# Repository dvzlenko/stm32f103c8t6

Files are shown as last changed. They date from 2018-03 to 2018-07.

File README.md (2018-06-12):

| stm32f103c8t6 | что подключать		|
|---|---|
| A8		| PWM_00			|
| A9		| PWM_01			|
| B12		| SENS_00			|
| B13		| SENS_01			|
| B14		| SENS_02			|
| B15		| SENS_03			|
| B8		| PWM_10			|
| B9		| PWM_11			|
| B6		| SENS_10			|
| B7		| SENS_11			|
| B10		| SENS_12			|
| B11		| SENS_13			|

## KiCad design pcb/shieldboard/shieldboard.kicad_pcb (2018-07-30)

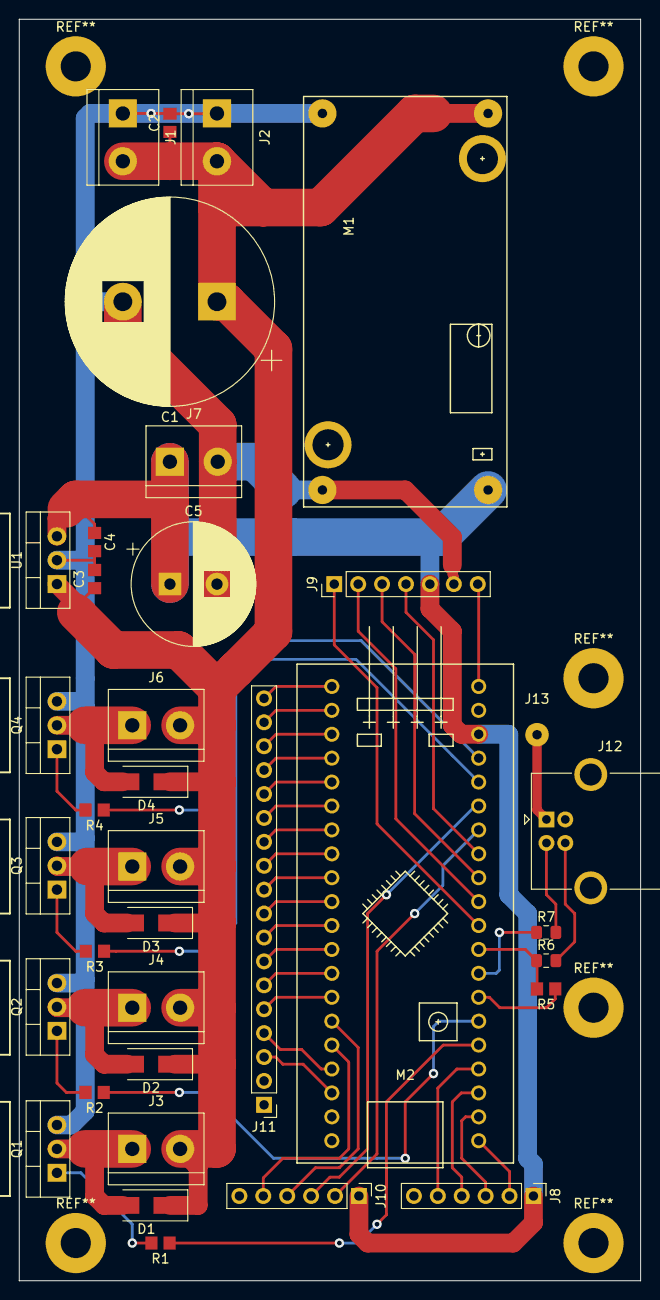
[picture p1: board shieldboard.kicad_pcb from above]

Board: 2 copper layers, 66.0 x 134.0 mm, 36 parts (0 on the bottom side), 50 nets.

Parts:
C1: 470,0x16; CP_Radial_D22.0mm_P10.00mm_SnapIn
C2, C3, C4: 0,1; C_0805_2012Metric_Pad1.29x1.40mm_HandSolder
C5: 10,0x16; CP_Radial_D13.0mm_P5.00mm
D1, D2, D3, D4: D; D_SMA_Handsoldering
J1, J2, J3, J4, J5, J6, J7: Conn_01x02; TerminalBlock_bornier-2_P5.08mm
J8, J10: Conn_01x06; PinHeader_1x06_P2.54mm_Vertical
J9: Conn_01x07; PinHeader_1x07_P2.54mm_Vertical
J11: Conn_01x18; PinHeader_1x18_P2.54mm_Vertical
J12: USB_B; USB_B_OST_USB-B1HSxx_Horizontal
J13: Conn_01x01; SolderWirePad_1x01_Drill1mm
M1: LM2596_DC-DC_module
M2: Maple_Mini
Q1, Q2, Q3, Q4: Q_NMOS_GDS; TO-220-3_Vertical
R1, R2, R3, R4: 100; R_0805_2012Metric_Pad1.29x1.40mm_HandSolder
R5: 1,5k; R_0805_2012Metric_Pad1.29x1.40mm_HandSolder
R6, R7: 22; R_0805_2012Metric_Pad1.15x1.40mm_HandSolder
U1: LM7805_TO220; TO-220-3_Vertical

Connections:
+5V: C4.1, C5.1, J7.1, J8.1, J9.5, J10.1, M1.OUT+, M2.18, U1.3
+12V: C1.1, C2.1, C3.1, D1.1, D2.1, D3.1, D4.1, J1.2, J2.2, J3.2, J4.2, J5.2, J6.2, M1.IN+, U1.1
GND: C1.2, C2.2, C3.2, C4.2, C5.2, J1.1, J2.1, J7.2, J8.6, J9.6, J10.6, J11.1, J11.2, J12.4, M1.IN-, M1.OUT-, M2.19, M2.39, M2.40, Q1.3, Q2.3, Q3.3, Q4.3, U1.2
unnamed: D1.2, J3.1, Q1.2
unnamed: D2.2, J4.1, Q2.2
unnamed: D3.2, J5.1, Q3.2
unnamed: D4.2, J6.1, Q4.2
unnamed: J8.2, M2.B12
unnamed: J8.3, M2.B13
unnamed: J8.4, M2.B14
unnamed: J8.5, M2.B15
unnamed: J9.1, M2.A15
unnamed: J9.2, M2.B3
unnamed: J9.3, M2.B4
unnamed: J9.4, M2.B5
unnamed: J9.7, M2.20
unnamed: J10.2, M2.B6
unnamed: J10.3, M2.B7
unnamed: J10.4, M2.B10
unnamed: J10.5, M2.B11
unnamed: J11.3, M2.38
unnamed: J11.4, M2.R
unnamed: J11.5, M2.B1
unnamed: J11.6, M2.B0
unnamed: J11.7, M2.A7
unnamed: J11.8, M2.A6
unnamed: J11.9, M2.A5
unnamed: J11.10, M2.A4
unnamed: J11.11, M2.A3
unnamed: J11.12, M2.A2
unnamed: J11.13, M2.A1
unnamed: J11.14, M2.A0
unnamed: J11.15, M2.C15
unnamed: J11.16, M2.C14
unnamed: J11.17, M2.C13
unnamed: J11.18, M2.VB
unnamed: J12.1, J13.1
unnamed: J12.2, R7.2
unnamed: J12.3, R6.2
unnamed: M2.A8, R1.1
unnamed: M2.A9, R2.1
unnamed: M2.A10, R5.1
unnamed: M2.A11, R7.1
unnamed: M2.A12, R5.2, R6.1
unnamed: M2.B8, R3.1
unnamed: M2.B9, R4.1
unnamed: Q1.1, R1.2
unnamed: Q2.1, R2.2
unnamed: Q3.1, R3.2
unnamed: Q4.1, R4.2

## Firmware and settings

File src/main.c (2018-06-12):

#include "hw_config.h"
#include "usb_lib.h"
#include "usb_desc.h"
#include "usb_pwr.h"
#include "stm32f10x_gpio.h"
#include "stdlib.h"
#include "cdcio.h"
#include "FreeRTOS.h"
#include "task.h"
#include "strtok.h"
#include "blink.h"
#include "adc.h"
#include "chat.h"
#include "flash.h"
#include "pwm.h"

#define USB_DP_PU_RCC	RCC_APB2Periph_GPIOA
#define USB_DP_PU_GPIO	GPIOA
#define USB_DP_PU_PIN	GPIO_Pin_10

static void usb_dp_pu()
{
	GPIO_InitTypeDef gpio_init = {
		.GPIO_Speed = GPIO_Speed_10MHz,
		.GPIO_Mode = GPIO_Mode_Out_PP,
		.GPIO_Pin = USB_DP_PU_PIN,
	};

	RCC_APB2PeriphClockCmd(USB_DP_PU_RCC, ENABLE);
	GPIO_Init(USB_DP_PU_GPIO, &gpio_init);
	GPIO_WriteBit(USB_DP_PU_GPIO, USB_DP_PU_PIN, Bit_SET);
}

int main(void)
{
	portBASE_TYPE err;
	char s[64];

	Set_USBClock();
	USB_Interrupts_Config();
	USB_Init();
	usb_dp_pu();

	flash_load();

	pwm_init(PWM0, 10000);
	pwm_init(PWM1, 10000);
	pwm_init(PWM2, 10000);

	err = xTaskCreate(vBlinkTask, "blink", 64, NULL,
			  tskIDLE_PRIORITY + 1, NULL );

	err = xTaskCreate(vChatTask, "chat", 256, NULL,
			  tskIDLE_PRIORITY + 1, NULL );

	err = xTaskCreate(pwm_ctl, "pwm", 256, NULL,
			  tskIDLE_PRIORITY + 1, NULL );

	vTaskStartScheduler();

	while(1)
		;
}

void vApplicationStackOverflowHook(xTaskHandle xTask,
			           signed portCHAR *pcTaskName )
{
	while(1)
		;
}

#ifdef USE_FULL_ASSERT
void assert_failed(uint8_t* file, uint32_t line)
{
/* User can add his own implementation to report the file name and line number,
 ex: printf("Wrong parameters value: file %s on line %d\r\n", file, line) */

	/* Infinite loop */
	while (1)
		;
}
#endif

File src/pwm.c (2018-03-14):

#include <stdint.h>
#include "stm32f10x_gpio.h"
#include "stm32f10x_tim.h"
#include "FreeRTOS.h"
#include "task.h"
#include "pwm.h"

extern uint32_t SystemCoreClock;

struct pwm {
	unsigned long	hz;
	unsigned long	period;

	GPIO_TypeDef	*gpio;
	uint16_t	gpio_pin;
	uint32_t	gpio_rcc;
	void (*gpio_rcc_init)(uint32_t, FunctionalState);

	uint32_t	afio_rcc;
	void (*afio_rcc_init)(uint32_t, FunctionalState);

	TIM_TypeDef *tim;
	uint32_t	tim_rcc;
	void (*tim_rcc_init)(uint32_t, FunctionalState);

	void (*init)(TIM_TypeDef *, TIM_OCInitTypeDef *);
};

static struct pwm pwm_list[NPWM] = {
	[PWM0] = {
		.gpio = GPIOA,
		.gpio_pin = GPIO_Pin_8,
		.gpio_rcc = RCC_APB2Periph_GPIOA,
		.gpio_rcc_init = RCC_APB2PeriphClockCmd,

		.afio_rcc = RCC_APB2Periph_AFIO,
		.afio_rcc_init = RCC_APB2PeriphClockCmd,

		.tim = TIM1,
		.tim_rcc = RCC_APB2Periph_TIM1,
		.tim_rcc_init = RCC_APB2PeriphClockCmd,
		.init = TIM_OC1Init,
	},
	[PWM1] = {
		.gpio = GPIOA,
		.gpio_pin = GPIO_Pin_9,
		.gpio_rcc = RCC_APB2Periph_GPIOA,
		.gpio_rcc_init = RCC_APB2PeriphClockCmd,

		.afio_rcc = RCC_APB2Periph_AFIO,
		.afio_rcc_init = RCC_APB2PeriphClockCmd,

		.tim = TIM1,
		.tim_rcc = RCC_APB2Periph_TIM1,
		.tim_rcc_init = RCC_APB2PeriphClockCmd,
		.init = TIM_OC2Init,
	},
	[PWM2] = {
		.gpio = GPIOA,
		.gpio_pin = GPIO_Pin_10,
		.gpio_rcc = RCC_APB2Periph_GPIOA,
		.gpio_rcc_init = RCC_APB2PeriphClockCmd,

		.afio_rcc = RCC_APB2Periph_AFIO,
		.afio_rcc_init = RCC_APB2PeriphClockCmd,

		.tim = TIM1,
		.tim_rcc = RCC_APB2Periph_TIM1,
		.tim_rcc_init = RCC_APB2PeriphClockCmd,
		.init = TIM_OC3Init,
	},
};

int pwm_init(enum pwm_id id, unsigned int hz)
{
	struct pwm *pwm;
	TIM_TimeBaseInitTypeDef ts;
	GPIO_InitTypeDef gs;

	if (id >= NPWM || hz > SystemCoreClock)
		return 1;

	pwm = &pwm_list[id];
	pwm->hz = hz;
	pwm->period = SystemCoreClock / hz - 1;

	if (pwm->period > 0xffff)
		return 1;

	pwm->tim_rcc_init(pwm->tim_rcc, ENABLE);
	pwm->gpio_rcc_init(pwm->gpio_rcc, ENABLE);
	pwm->afio_rcc_init(pwm->afio_rcc, ENABLE);

	gs.GPIO_Pin = pwm->gpio_pin;
	gs.GPIO_Mode = GPIO_Mode_AF_PP;
	gs.GPIO_Speed = GPIO_Speed_50MHz;
	GPIO_Init(pwm->gpio, &gs);

	ts.TIM_Prescaler = 0;
	ts.TIM_CounterMode = TIM_CounterMode_Up;
	ts.TIM_Period = pwm->period;
	ts.TIM_ClockDivision = 0;
	ts.TIM_RepetitionCounter = 0;
	TIM_TimeBaseInit(pwm->tim, &ts);

	pwm_set(id, 0);

	return 0;
}

int pwm_set(enum pwm_id id, unsigned int dc)
{
	struct pwm *pwm;
	TIM_OCInitTypeDef  ocs;

	if (id >= NPWM || dc > 100)
		return 1;

	pwm = &pwm_list[id];

	ocs.TIM_OCMode = TIM_OCMode_PWM2;
	ocs.TIM_OutputState = TIM_OutputState_Enable;
	ocs.TIM_OutputNState = TIM_OutputNState_Enable;
	ocs.TIM_Pulse = pwm->period * dc / 100;
	ocs.TIM_OCPolarity = TIM_OCPolarity_Low;
	ocs.TIM_OCNPolarity = TIM_OCNPolarity_High;
	ocs.TIM_OCIdleState = TIM_OCIdleState_Set;
	ocs.TIM_OCNIdleState = TIM_OCIdleState_Reset;
	pwm->init(pwm->tim, &ocs);

	TIM_Cmd(pwm->tim, ENABLE);
	TIM_CtrlPWMOutputs(pwm->tim, ENABLE);

	return 0;
}

#define SENS_GPIO	GPIOB
#define SENS_RCC	RCC_APB2Periph_GPIOB
#define SENS_RCC_INIT	RCC_APB2PeriphClockCmd

#define SENS_PIN1	GPIO_Pin_12
#define SENS_PIN2	GPIO_Pin_13
#define SENS_PIN3	GPIO_Pin_14
#define SENS_PIN4	GPIO_Pin_15
#define SENS_PIN5	GPIO_Pin_11

#define SENS_PINS	(SENS_PIN1 | SENS_PIN2 | SENS_PIN3 | SENS_PIN4 | SENS_PIN5)

#define PWM_DEL		((200 * configTICK_RATE_HZ) / 1000)
#define PWM_DC1		70
#define PWM_DC		40

#define GATE_TIMEOUT		(3 * 60 * configTICK_RATE_HZ)

void gate_open(enum pwm_id pwm)
{
	pwm_set(pwm, 0);
}

void gate_close(enum pwm_id pwm)
{
	pwm_set(pwm, PWM_DC1);
	vTaskDelay(PWM_DEL);
	pwm_set(pwm, PWM_DC);
}

void gate_reset()
{
	gate_open(PWM0);
	gate_close(PWM1);
}

#define gate_timeout_restart()				\
do {							\
	now = xTaskGetTickCount();			\
	gate_timeout = now + GATE_TIMEOUT;		\
	tick_wrap = gate_timeout < now ? 1 : 0;		\
} while (0)

void pwm_ctl(void *vpars)
{
	int gate_count = 0, tick_wrap, state = 0;
	portTickType t, now, gate_timeout;
	unsigned long sens = 0, sens_old = 0;
	GPIO_InitTypeDef gs = {
		.GPIO_Pin = SENS_PINS,
		.GPIO_Mode = GPIO_Mode_IPD,
		.GPIO_Speed = GPIO_Speed_50MHz,
	};

	SENS_RCC_INIT(SENS_RCC, ENABLE);
	GPIO_Init(SENS_GPIO, &gs);

	t = xTaskGetTickCount();
	gate_reset();

	while (1) {
		unsigned long s;

		vTaskDelay(100);

		now = xTaskGetTickCount();
		if (now < t)
			tick_wrap = 0;
		t = now;

		sens_old = sens;
		s = GPIO_ReadInputData(SENS_GPIO);
		sens = 0;
		if (s & SENS_PIN1)
			sens |= 1;
		if (s & SENS_PIN2)
			sens |= 2;
		if (s & SENS_PIN3)
			sens |= 4;
		if (s & SENS_PIN4)
			sens |= 8;
		if (s & SENS_PIN5)
			sens |= 0x10;

		if (!(sens ^ sens_old))
			continue;

		if (state == 0 && (sens & 7) == 4) {
			state = 1;
			gate_close(PWM0);
			gate_open(PWM1);
		}

		if (state == 1 && (sens & 0x18) == 0x18)
			state = 2;

		if (state == 2 && (sens & 0x18) == 0x10)
			state = 3;

		if (state == 3 && (sens & 0x18) == 0) {
			state = 0;
			gate_reset();
		}
	}
}

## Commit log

2018-03-14 fixup! implement gate control algorithm
    [pwm.c]
2018-03-14 gate control: reset gate upon 4th sensor crossing
    [pwm.c]
2018-03-14 gate control: use two sensors to detect a rat has left the maze
2018-06-12 WIP: add pcb design files
    [gateboard.kicad_pcb, gateboard.sch, shieldboard.kicad_pcb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]
2018-06-12 pcb: connect uC board to the shield
    [shieldboard.sch]
2018-07-30 pcb: update
    [shieldboard-2018-06-16-02-10-35.sch, shieldboard.kicad_pcb, shieldboard.sch]
